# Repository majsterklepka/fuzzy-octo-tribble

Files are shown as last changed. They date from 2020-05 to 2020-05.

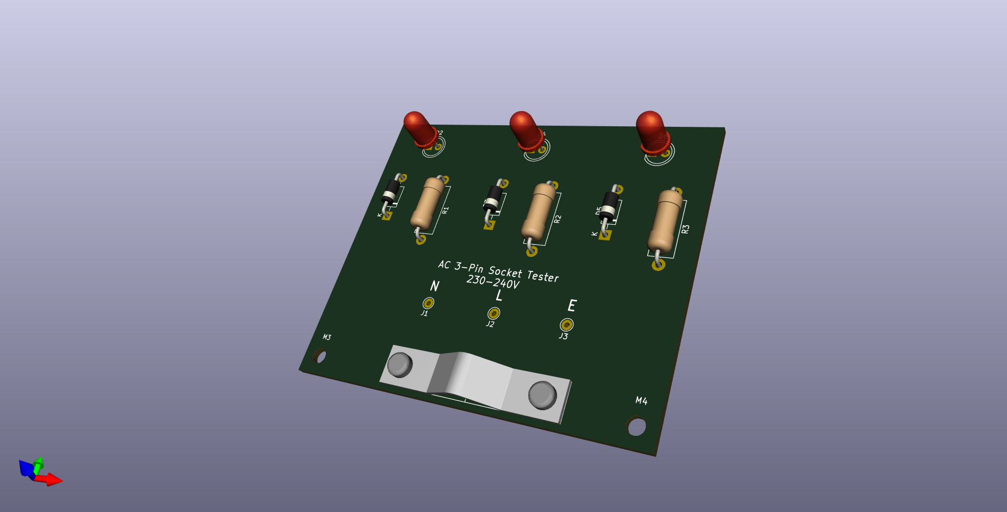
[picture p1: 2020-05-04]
KiCad/DIY-AC-3-Pin-Socket-Tester/DIY-AC-3-Pin-Socket-Tester.png

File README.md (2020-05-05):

# Electrical equipments
diy ac 3-pin socket tester

Hi, Jak się macie?

Zaprezentuje Wam dziś projekt testera gniazd sieciowych 230-240V. Projekt zaczerpnięty z [instructables.com](https://www.instructables.com/id/DIY-AC-3-Pin-Socket-Tester/ "Instructables.com").

Z uwagi na fakt, że projekt dotyczy kontaktu z siecią prądu przemiennego 230V(Europa), wykonanie go wymaga ogromnego doświadczenia i pewnej, dość dużej wprawy w pracach z napięciem sieciowym.

Do wykonania, potrzeba:
- trzy rezystory 2W, 47k
- trzy diody LED,
- trzy zwykłe diody prostownicze, o napięciu wstecznym min. 1000V i prądzie min. 1A
- płytka drukowana według dokumentacji zawartej w katalogu [KiCad](/KiCad "Dokumentacja")
- obudowa, wykonana na drukarce 3D, [obudowa STL](/3dhousing "3Dhousing")
- mocowania kabla testowego, [Dokumentacja -> blaszka, obudowa](/mechanical "mechanical")
- kabel sieciowy, zalewany, trzy-żyłowy, z wtyczką, z uziemieniem

## Krótka instrukcja obsługi

| LED1 |LED2 | LED3 | opis |
| :---: | :---: | :---: | :--- |
| X | X | | wszystko OK |
| X | | | niepodłączona ziemia(E) |
| | X | X | sieć(L) - ziemia(E) odwrócone |
| X | | X | sieć(L) - zero(N) odwrócone |
| | X | | brak zero(N) |
| | | | brak sieci(L)/brak zero(N) i brak ziemi(E) | 

## Credits

Jak zwykle i ten projekt jest dostępny na zasadach Wolnych Licencji:
- [CC-BY-SA 4.0](https://creativecommons.org/licenses/by-sa/4.0/ "license")

>:warning:**Uwaga!!!**  
>
>W układzie występuje niebezpieczne dla życia napięcie sieciowe!  
>Po montażu, płytkę drukowaną należy zaizolować lakierem poliuretanowym!  
>a elementy obudowy, wieko z puszką obudowy skleić!  
>przepust należy wypełnić silikonem!  

- - - 

Baw się dobrze, czuj się wolny i pamiętaj o Autorze(ach)! Podziel się tym projektem ze swoimi przyjaciółmi.

_Msc. Paweł Sobótka (SQ7EQE)_

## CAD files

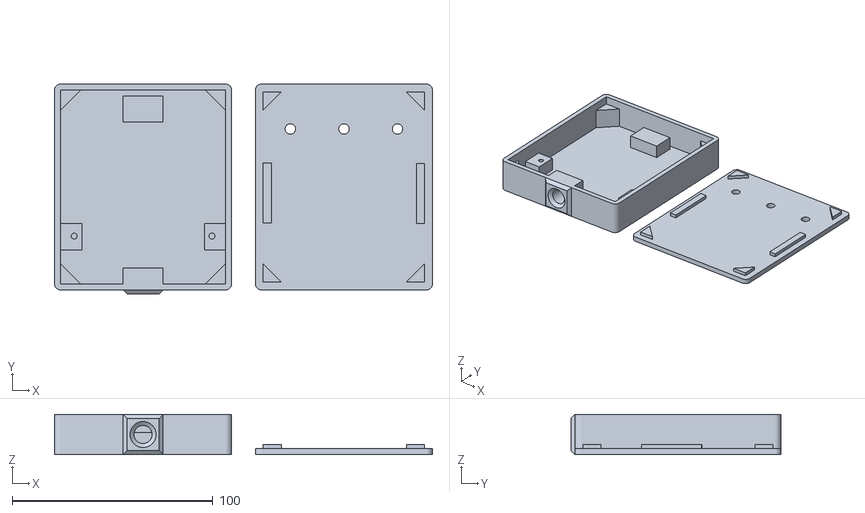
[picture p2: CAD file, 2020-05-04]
3dhousing/diy-ac-tester.stl
188.2 x 104.5 x 20.0

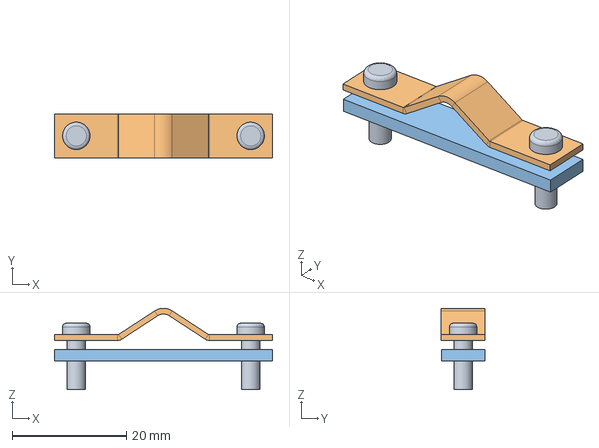
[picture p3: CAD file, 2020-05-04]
KiCad/DIY-AC-3-Pin-Socket-Tester/3dpackage/net-conn.step
38.1 x 7.74 x 14.2 mm

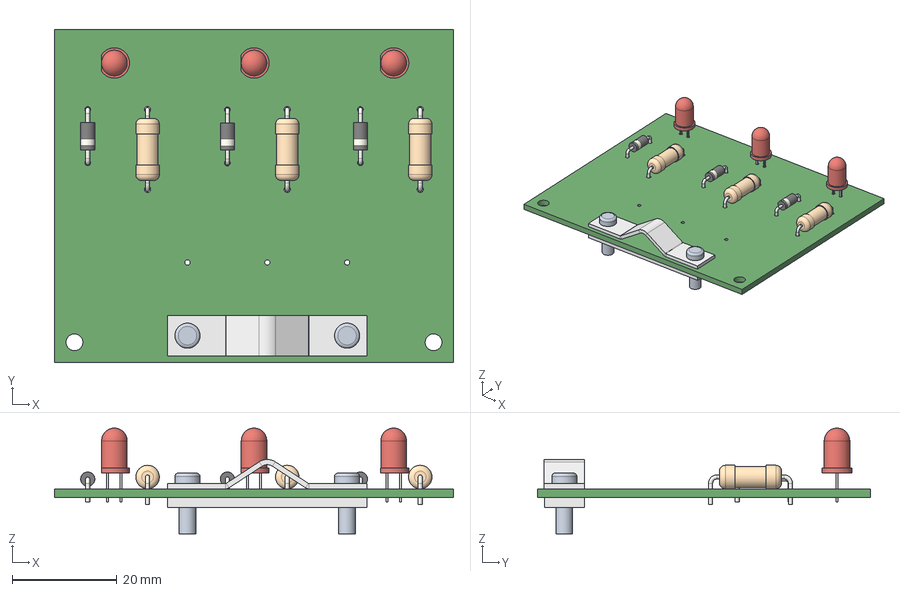
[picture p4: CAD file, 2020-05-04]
KiCad/DIY-AC-3-Pin-Socket-Tester/DIY-AC-3-Pin-Socket-Tester.step
76.2 x 63.5 x 20.2 mm

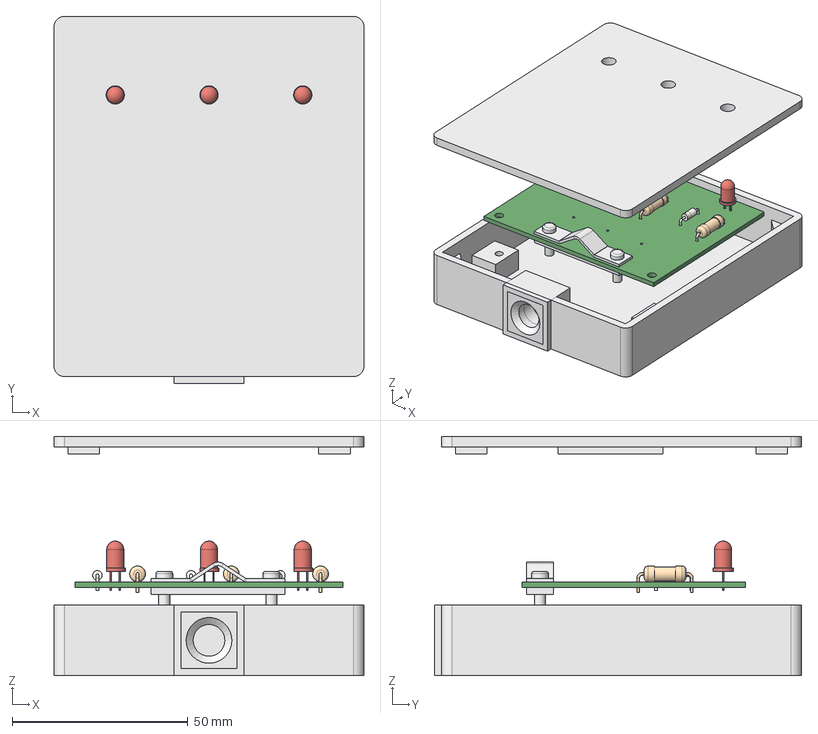
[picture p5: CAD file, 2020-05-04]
mechanical/3dhousing.FCStd
88.2 x 104.5 x 68.0 mm

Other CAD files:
mechanical/net-cable-conn.FCStd

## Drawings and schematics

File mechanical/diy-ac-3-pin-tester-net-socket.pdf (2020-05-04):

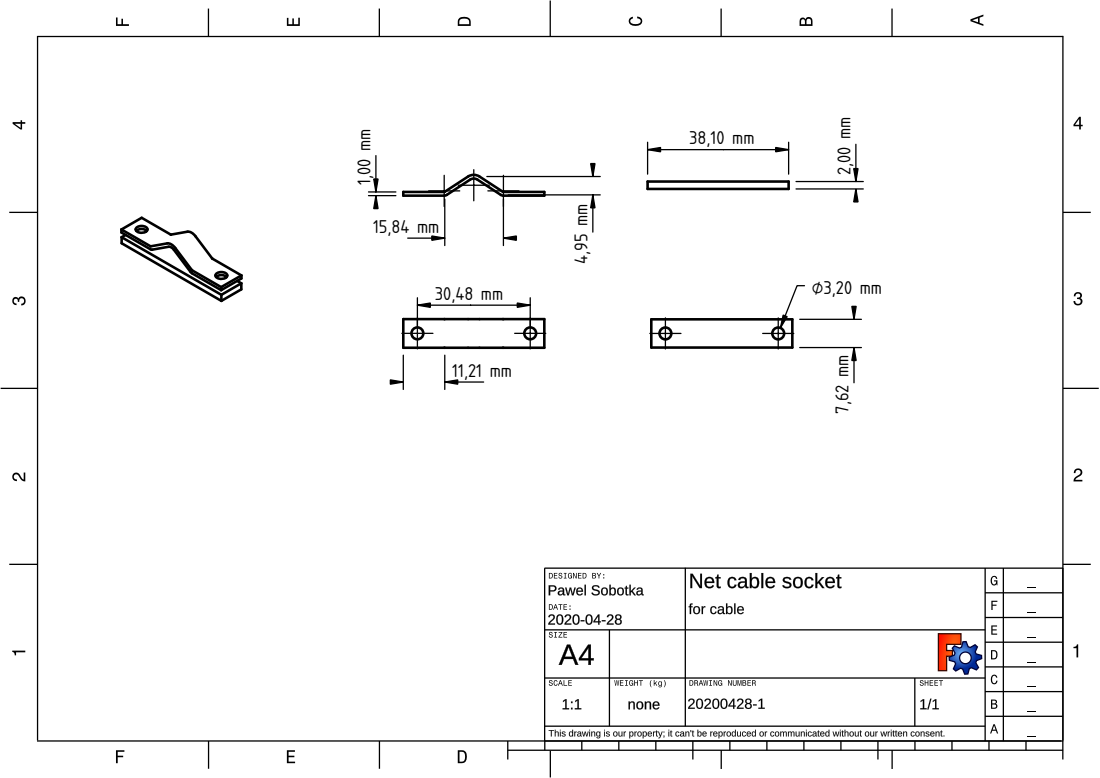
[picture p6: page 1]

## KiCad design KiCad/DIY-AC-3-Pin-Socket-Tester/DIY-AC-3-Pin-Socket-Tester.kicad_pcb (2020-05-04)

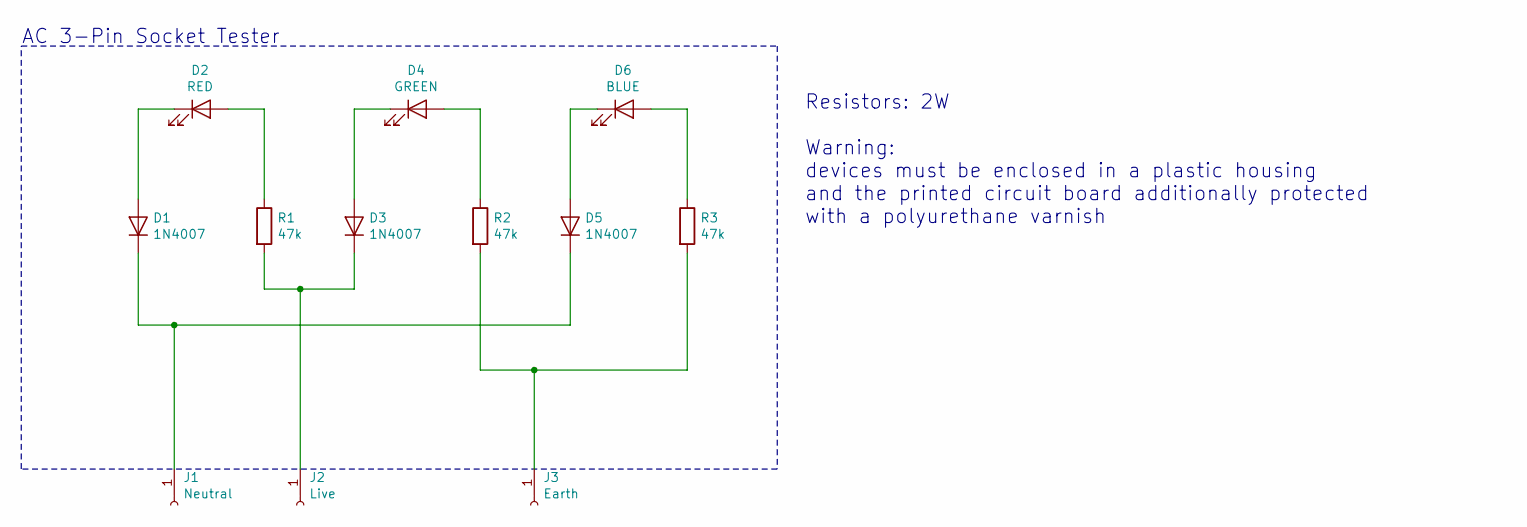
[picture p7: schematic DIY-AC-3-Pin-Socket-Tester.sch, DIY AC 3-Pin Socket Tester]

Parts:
D1, D3, D5: 1N4007; D_DO-41_SOD81_P10.16mm_Horizontal
D2: RED; LED_D5.0mm
D4: GREEN; LED_D5.0mm
D6: BLUE; LED_D5.0mm
J1: Neutral; Pin_D1.0mm_L10.0mm
J2: Live; Pin_D1.0mm_L10.0mm
J3: Earth; Pin_D1.0mm_L10.0mm
R1, R2, R3: 47k; R_Axial_DIN0414_L11.9mm_D4.5mm_P15.24mm_Horizontal

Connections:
unnamed: D1.1 (K), D5.1 (K), J1.1
unnamed: D1.2 (A), D2.1 (K)
unnamed: D2.2 (A), R1.1
unnamed: D3.1 (K), J2.1, R1.2
unnamed: D3.2 (A), D4.1 (K)
unnamed: D4.2 (A), R2.1
unnamed: D5.2 (A), D6.1 (K)
unnamed: D6.2 (A), R3.1
unnamed: J3.1, R2.2, R3.2

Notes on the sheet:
Resistors: 2W Warning: devices must be enclosed in a plastic housing and the printed circuit board additionally protected with a polyurethane varnish
AC 3-Pin Socket Tester

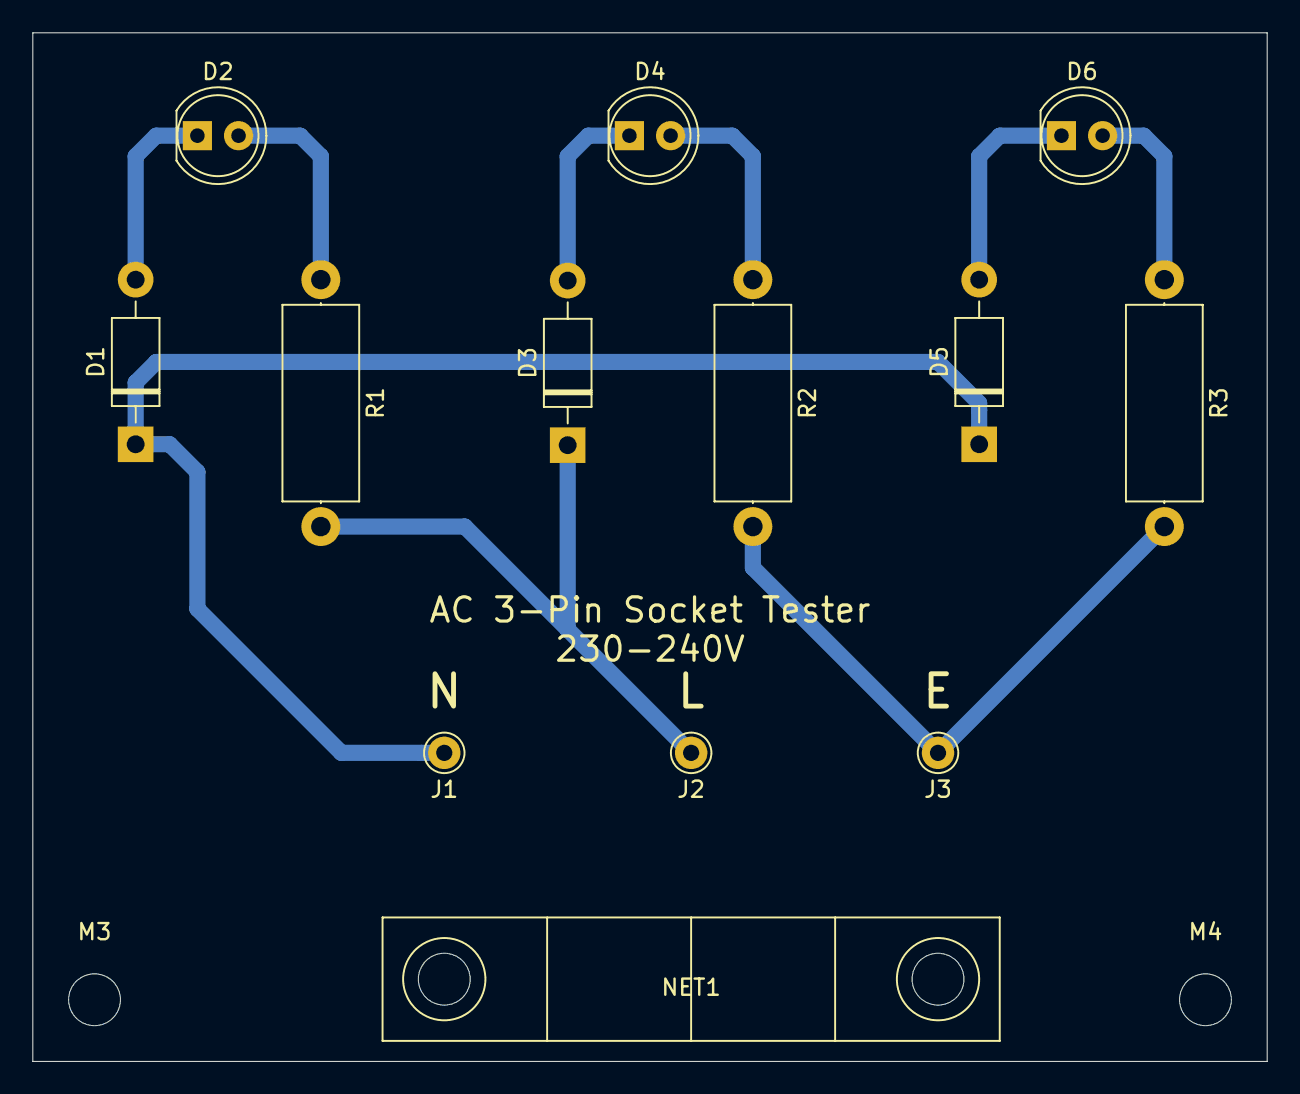
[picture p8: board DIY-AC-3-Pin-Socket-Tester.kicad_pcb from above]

Board: 2 copper layers, 76.2 x 63.5 mm, 15 parts (0 on the bottom side), 9 nets.

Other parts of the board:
M3, M4: MountingHole_3.2mm_M3
NET1: net-cable-conn
